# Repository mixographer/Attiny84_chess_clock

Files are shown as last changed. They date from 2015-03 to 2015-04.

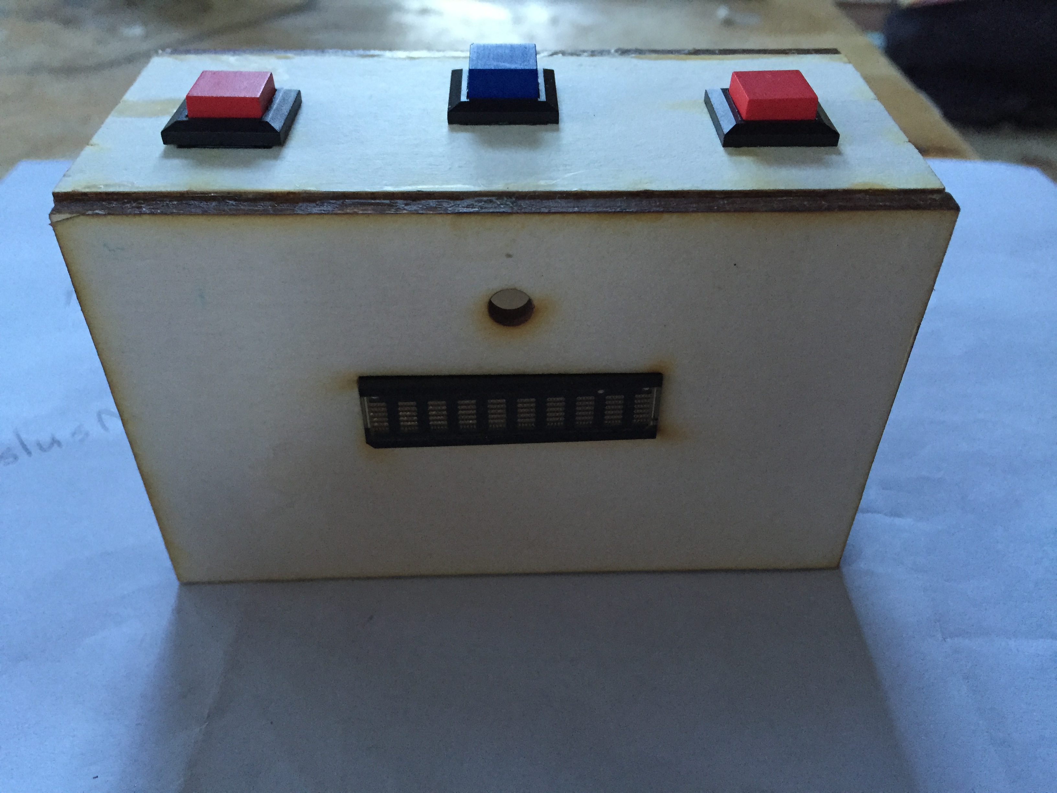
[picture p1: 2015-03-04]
Images/laser_cut_test.JPG

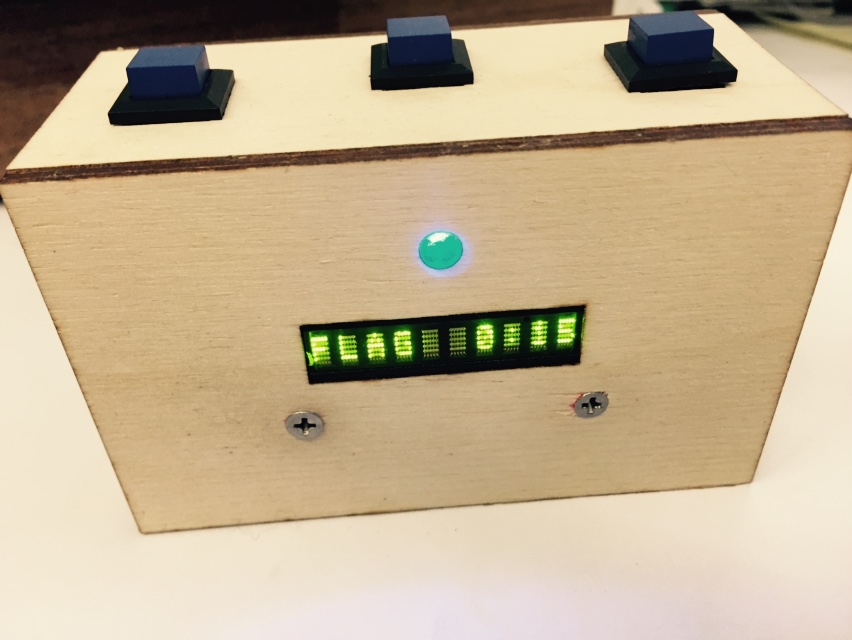
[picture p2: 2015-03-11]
Images/simple_clock.JPG

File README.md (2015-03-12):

# Attiny84 Chess Clock
A chess clock based on the Atmel Attiny84 micorcontroller.

This project is a simple chess clock based on the Atmel Attiny84 micoprocessor. It uses the SCD55104 LED Display 
module to display player times and user interface menus. The time periods are adjustable and the clock operated 
in three different modes. 

# Modes
## Sudden Death
In Sudden-death mode, your clock runs when it is your turn, and you lose when you run out of time. 

## Fischer Increment
In Fischer Increment mode, an increment is added at the start of each turn. In Fischer Increment mode you can actually 
add time to your total if you move faster than the increment amount. 

## Hourglass
In Hourglass mode, as one player's time goes down, the other player's time goes up. 

# Operation 
The Chess Clock has four buttons that are used during gameplay, and to set the parameters of the clock. 
1. Start/Reset
2. Player 1/Down
3. Player 2/Up
4. Pause/Enter

## Start
To begin using the clock press the Start/Reset button. 

## Set Time
You will be prompted to set the time period for the game with the text "Set Time:" Use the 'Player 1/Down' and 'Player 2/Up' buttons to set the time period. The default time is 2 minutes. The 'down' button reduces the time period while the 'up' button adds time. If the current time setting is 1:00 the down button will reduce the time period by 50%. The 'up' button adds 1 minute to the time period. 

When you have set the desired time period with the 'down' and 'up' buttons, press the 'Pause/Enter' button to accept the time period. 

## Set Mode
You will be prompted to set the mode of the clock.

#### Sudden Death
The default mode is Sudden Death or Guillotine. If you would like this mode simply hit the "Pause/Enter" button. 
The time period will be displayed for both players, and a play can begin. You can also scroll through the all modes with the 'Player 1/Down' and Player 2/Up' buttons. 

#### Fischer Increment
Fischer increment mode can be selected by pressing the 'Player 1/Down' or 'Player2/Up button at the 'Set Mode' prompt. When 'Fischer' is displayed on the clock you can accept Fischer delay mode by pressing the 'Pause/Enter' button. 

Set the increment. 
In Fischer increment mode, an increment period is required. The clock will prompt for the increment with the display "Inc?: 0:05." Set the desired increment with the 'Player 1/Down' and 'Player 2/Up' buttons. The increment adjusts in 1 second increments. Accept the increment with the 'Pause/Enter' button, the time period will be displayed and play can begin.

#### Hourglass
Hourglass mode can be selected by pressing the 'Player 1/Down' or 'Player2/Up' button at the 'Set Mode' prompt. Hourglass mode operates like an hourglass. As time is decreasing for one player, it is increasing for the other player. Once 'Hourglass' is displayed, press the 'Pause/Enter' button and play can begin. 

## Play
Once the time period and mode have been set, the clock is ready to use. When time runs out for a player and indicator light will illuminate and the word "FLAG" will appear for the player who ran out of time. After a short period of time the clock will shut down. To start a new game, press the 'Start/Reset' button. 

If during play, the clock needs to be paused for any reason, the 'Pause/Enter' will stop the clock at the current time. Play may be restarted by pressing either the 'Player1' or 'Player 2' button. Do not leave the clock paused for extended periods of time as that will prevent the clock from powering down and will drain the batteries. 

###Keywords
Chess Clock, DIY Chess Clock, Atmel, Attiny, Blitz, Bullet, Chess.

- - - 
### License
Licensed under the MIT License. See LICENSE.txt.

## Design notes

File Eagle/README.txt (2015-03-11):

I have tested 'scd55104_chess_clock.brd' and it works fine. I have not yet received 'Chess_Clock_Larger.brd' back from the board house, so I don't know if it works.

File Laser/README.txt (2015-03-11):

This SVG file (box_final_3mm_revised.svg) can be used as an enclosure for the Chess Clock. The original file box_final_3mm.svg had some errors in the side panels. Do not use that file.

I had enclosures cut from these files at Pololu.com. 

Note: I have not had this exact file laser cut. I have revised it to include the mounting holes 
on the front face. I have printed the drawings and compared them to the basic board 'scd55104_chess_clock.brd' They look good, but double check them if you are going to send them off to be cut. 

I have also not made an enclosure for 'Chess_Clock_Larger.brd' as of yet.

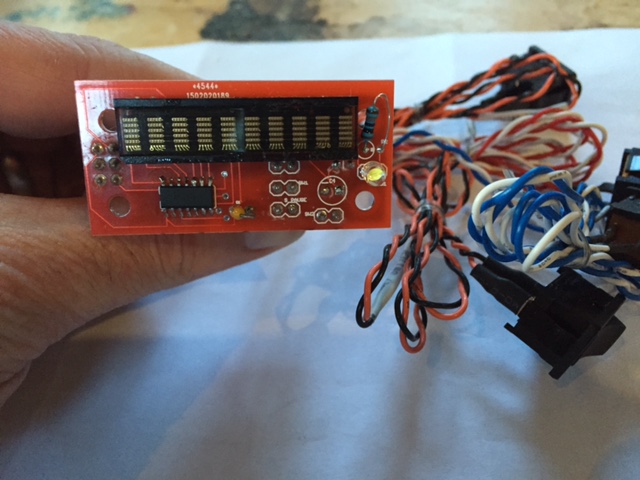
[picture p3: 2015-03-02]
Images/board_hookup.JPG

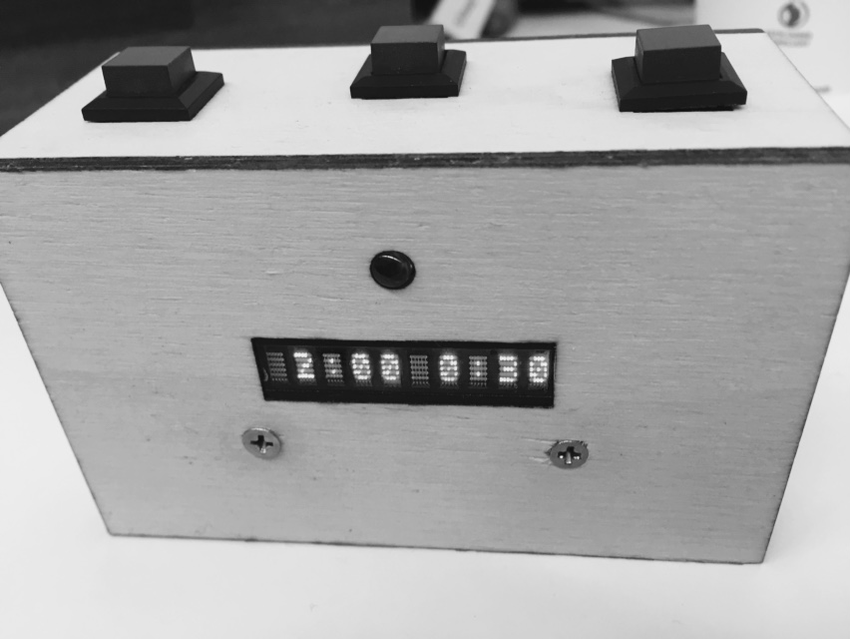
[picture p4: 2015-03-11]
Images/simple_clock_bw.JPG

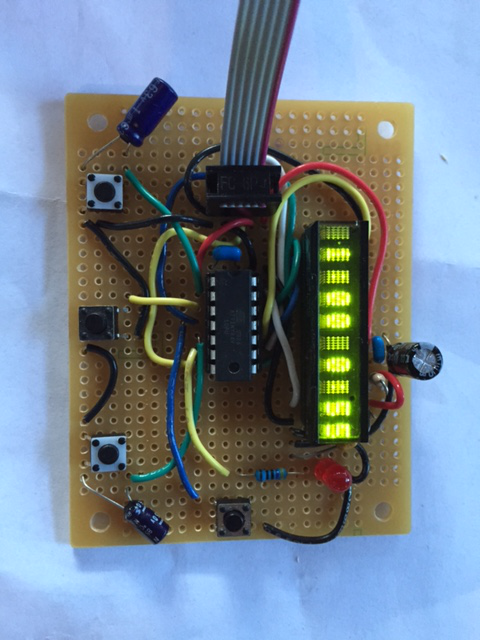
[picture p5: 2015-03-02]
Images/perf_board.JPG

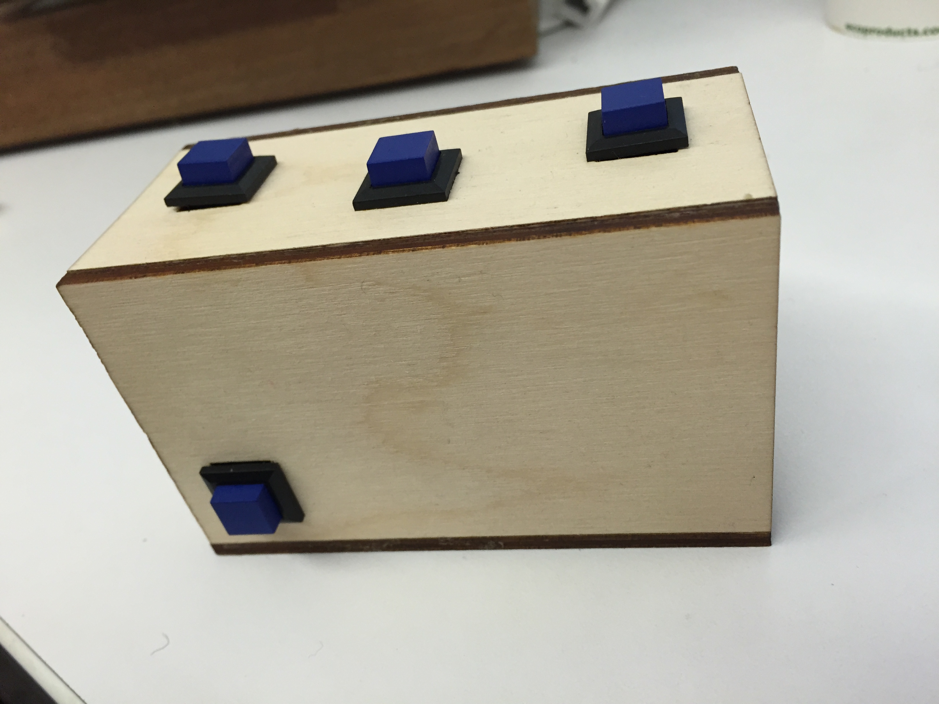
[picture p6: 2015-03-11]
Images/simple_clock_back.JPG

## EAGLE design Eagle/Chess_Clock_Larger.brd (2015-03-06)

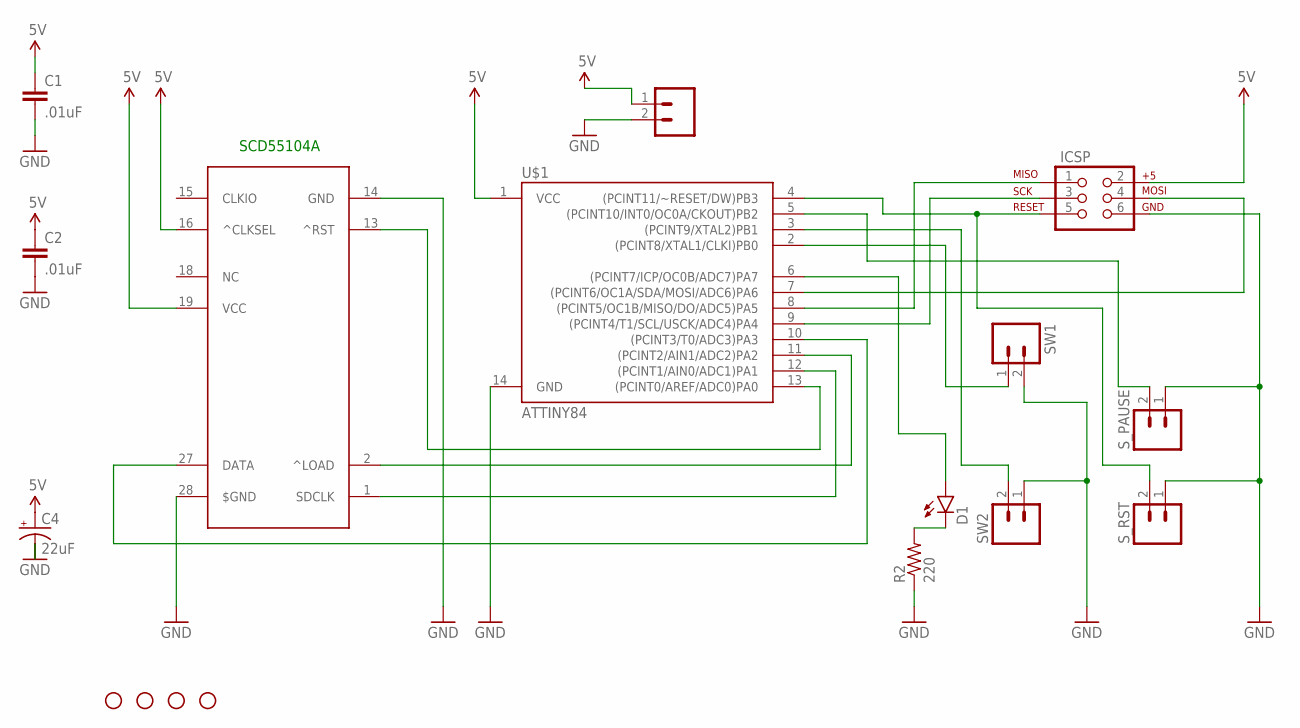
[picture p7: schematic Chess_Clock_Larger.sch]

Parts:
C1, C2: .01uF; CAP-PTH-SMALL
C4: 22uF; CPOL-RADIAL-10UF-25V
D1: LED5MM
ICSP: AVR_SPI_PRG_6PTH; 2X3
R2: 220; 1206
SCD55104A: SCD_55104A; SCD55104A
STANDOFF1, STANDOFF2, STANDOFF3, STANDOFF4: STAND-OFF
SW1, SW2, SW3: M02PTH; 1X02
S_PAUSE: M02PTH; 1X02
S_RST: M02PTH; 1X02
U$1: ATTINY84; SO14

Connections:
5V: C1.1, C2.1, C4.1 (+), ICSP.2, SCD55104A.16 (^CLKSEL), SCD55104A.19 (VCC), SW3.1, U$1.1 (VCC)
GND: C1.2, C2.2, C4.2 (-), ICSP.6, R2.1, SCD55104A.14 (GND), SCD55104A.28 ($GND), SW1.2, SW2.1, SW3.2, S_PAUSE.1, S_RST.1, U$1.14 (GND)
unnamed: D1.K (C), R2.2
unnamed: SCD55104A.13 (^RST), U$1.13 ((PCINT0/AREF/ADC0)PA0)
unnamed: ICSP.4, U$1.7 ((PCINT6/OC1A/SDA/MOSI/ADC6)PA6)
unnamed: ICSP.5, S_RST.2, U$1.4 ((PCINT11/~RESET/DW)PB3)
unnamed: ICSP.1, U$1.8 ((PCINT5/OC1B/MISO/DO/ADC5)PA5)
unnamed: ICSP.3, U$1.9 ((PCINT4/T1/SCL/USCK/ADC4)PA4)
unnamed: SCD55104A.1 (SDCLK), U$1.12 ((PCINT1/AIN0/ADC1)PA1)
unnamed: SCD55104A.2 (^LOAD), U$1.11 ((PCINT2/AIN1/ADC2)PA2)
unnamed: SW1.1, U$1.2 ((PCINT8/XTAL1/CLKI)PB0)
unnamed: SW2.2, U$1.3 ((PCINT9/XTAL2)PB1)
unnamed: S_PAUSE.2, U$1.5 ((PCINT10/INT0/OC0A/CKOUT)PB2)
unnamed: D1.A, U$1.6 ((PCINT7/ICP/OC0B/ADC7)PA7)
unnamed: SCD55104A.27 (DATA), U$1.10 ((PCINT3/T0/ADC3)PA3)

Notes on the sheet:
SCD55104A

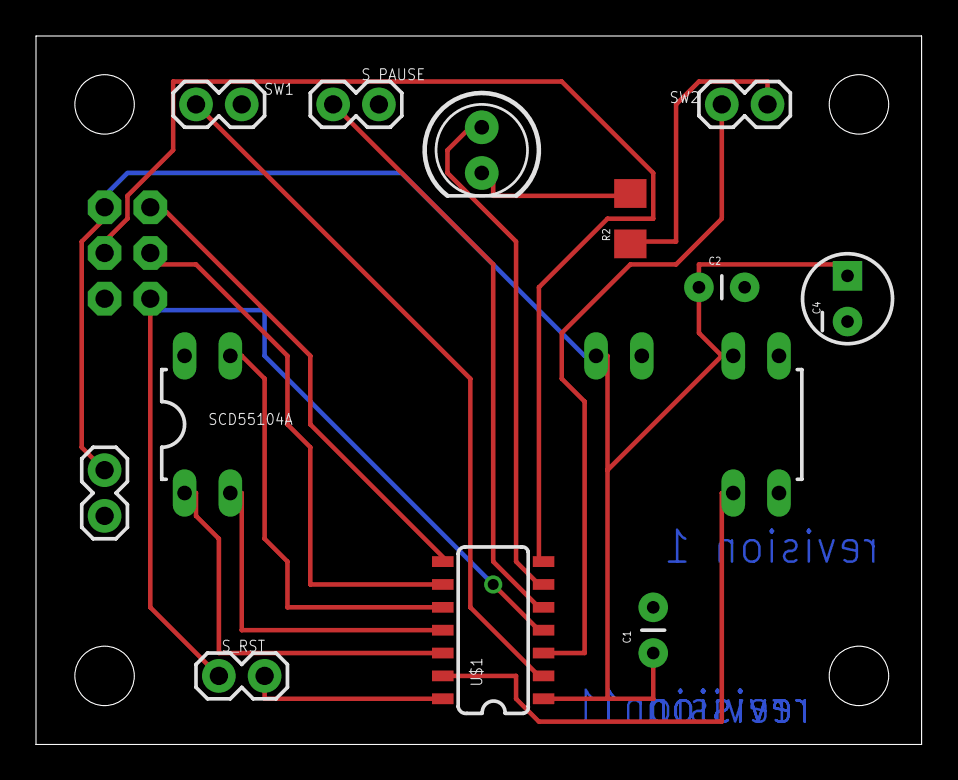
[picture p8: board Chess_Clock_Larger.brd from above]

Board: 2 copper layers, 49.2 x 39.4 mm, 17 parts (1 on the bottom side), 15 nets.

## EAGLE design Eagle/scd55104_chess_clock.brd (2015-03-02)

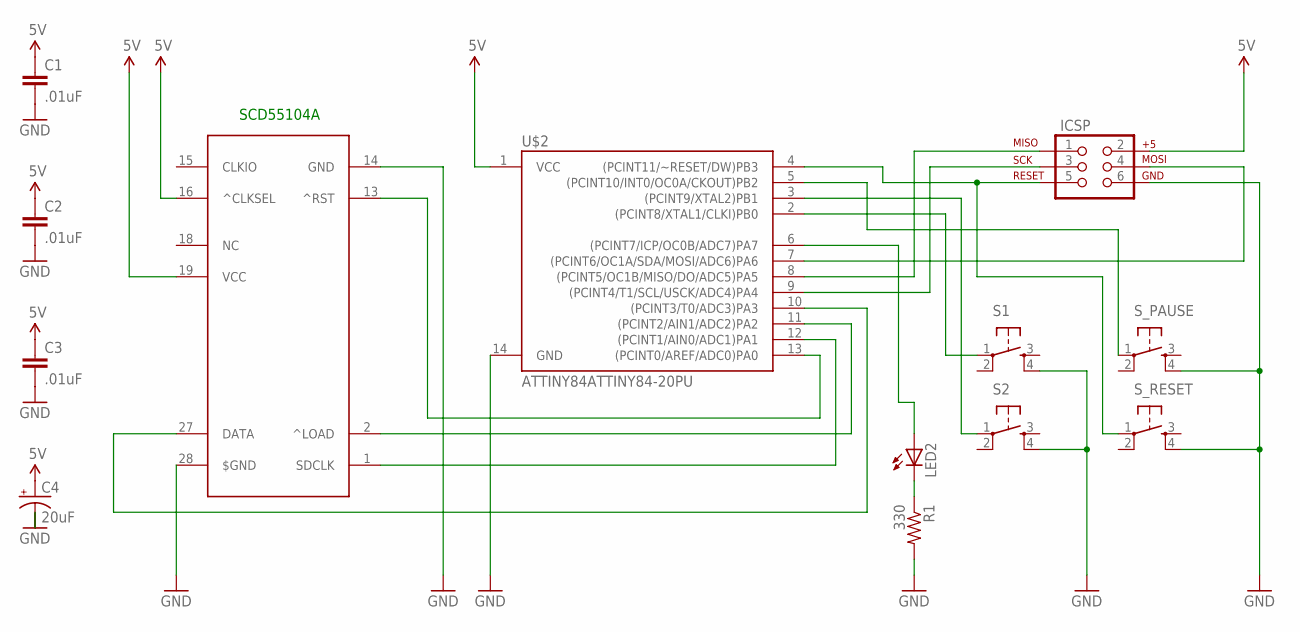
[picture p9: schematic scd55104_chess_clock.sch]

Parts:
C1, C2, C3: .01uF; CAP-PTH-SMALL
C4: 20uF; CPOL-RADIAL-10UF-25V
ICSP: AVR_SPI_PRG_6PTH; 2X3
LED2: LED3MM
R1: 330; AXIAL-0.4
S1, S2: TAC_SWITCHPTH; TACTILE-PTH
SCD55104A: SCD_55104A; SCD55104A
S_PAUSE: TAC_SWITCHPTH; TACTILE-PTH
S_RESET: TAC_SWITCHPTH; TACTILE-PTH
U$2: ATTINY84ATTINY84-20PU; DIL14

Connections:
5V: C1.1, C2.1, C3.1, C4.1 (+), ICSP.2, SCD55104A.16 (^CLKSEL), SCD55104A.19 (VCC), U$2.1 (VCC)
GND: C1.2, C2.2, C3.2, C4.2 (-), ICSP.6, R1.P$2 (2), S1.4, S2.4, SCD55104A.14 (GND), SCD55104A.28 ($GND), S_PAUSE.4, S_RESET.4, U$2.14 (GND)
unnamed: SCD55104A.13 (^RST), U$2.13 ((PCINT0/AREF/ADC0)PA0)
unnamed: ICSP.4, U$2.7 ((PCINT6/OC1A/SDA/MOSI/ADC6)PA6)
unnamed: ICSP.5, S_RESET.1, U$2.4 ((PCINT11/~RESET/DW)PB3)
unnamed: ICSP.1, U$2.8 ((PCINT5/OC1B/MISO/DO/ADC5)PA5)
unnamed: ICSP.3, U$2.9 ((PCINT4/T1/SCL/USCK/ADC4)PA4)
unnamed: SCD55104A.1 (SDCLK), U$2.12 ((PCINT1/AIN0/ADC1)PA1)
unnamed: SCD55104A.2 (^LOAD), U$2.11 ((PCINT2/AIN1/ADC2)PA2)
unnamed: S1.1, U$2.2 ((PCINT8/XTAL1/CLKI)PB0)
unnamed: S2.1, U$2.3 ((PCINT9/XTAL2)PB1)
unnamed: LED2.K (C), R1.P$1 (1)
unnamed: S_PAUSE.1, U$2.5 ((PCINT10/INT0/OC0A/CKOUT)PB2)
unnamed: LED2.A, U$2.6 ((PCINT7/ICP/OC0B/ADC7)PA7)
unnamed: SCD55104A.27 (DATA), U$2.10 ((PCINT3/T0/ADC3)PA3)

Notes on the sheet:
SCD55104A

Board: 2 copper layers, 13 parts (0 on the bottom side), 15 nets, no tracks yet.

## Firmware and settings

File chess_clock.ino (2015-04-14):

#include <avr/sleep.h>
#include <avr/pgmspace.h>
#include <avr/power.h>


//standard ascii 5x5 font
static unsigned char Font5x5[] PROGMEM = {
  0x00, 0x20, 0x40, 0x60, 0x80,
  0x04, 0x24, 0x44, 0x60, 0x84,
  0x0A, 0x2A, 0x40, 0x60, 0x80,
  0x0A, 0x3F, 0x4A, 0x7F, 0x8A,
  0x0F, 0x34, 0x4E, 0x65, 0x9E,
  0x19, 0x3A, 0x44, 0x6B, 0x93,
  0x08, 0x34, 0x4D, 0x72, 0x8D,
  0x04, 0x24, 0x40, 0x60, 0x80,
  0x02, 0x24, 0x44, 0x64, 0x82,
  0x08, 0x24, 0x44, 0x64, 0x88,
  0x15, 0x2E, 0x5F, 0x6E, 0x95,
  0x04, 0x24, 0x5F, 0x64, 0x84,
  0x00, 0x20, 0x40, 0x64, 0x84,
  0x00, 0x20, 0x4E, 0x60, 0x80,
  0x00, 0x20, 0x40, 0x60, 0x84,
  0x01, 0x22, 0x44, 0x68, 0x90,
  0x0E, 0x33, 0x55, 0x79, 0x8E,
  0x04, 0x2C, 0x44, 0x64, 0x8E,
  0x1E, 0x21, 0x46, 0x68, 0x9F,
  0x1E, 0x21, 0x4E, 0x61, 0x9E,
  0x06, 0x2A, 0x5F, 0x62, 0x82,
  0x1F, 0x30, 0x5E, 0x61, 0x9E,
  0x06, 0x28, 0x5E, 0x71, 0x8E,
  0x1F, 0x22, 0x44, 0x68, 0x88,
  0x0E, 0x31, 0x4E, 0x71, 0x8E,
  0x0E, 0x31, 0x4F, 0x62, 0x8C,
  0x00, 0x24, 0x40, 0x64, 0x80,
  0x00, 0x24, 0x40, 0x6C, 0x80,
  0x02, 0x24, 0x48, 0x64, 0x82,
  0x00, 0x3F, 0x40, 0x7F, 0x80,
  0x08, 0x24, 0x42, 0x64, 0x88,
  0x0E, 0x31, 0x42, 0x64, 0x84,
  0x0E, 0x35, 0x57, 0x70, 0x8E,
  0x04, 0x2A, 0x5F, 0x71, 0x91,   
  0x1E, 0x29, 0x4E, 0x69, 0x9E,   
  0x0F, 0x30, 0x50, 0x70, 0x8F,   
  0x1E, 0x29, 0x49, 0x69, 0x9E,   
  0x1F, 0x30, 0x5E, 0x70, 0x9F,   
  0x1F, 0x30, 0x5E, 0x70, 0x90,   
  0x0F, 0x30, 0x53, 0x71, 0x8F,   
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
};

//Display pins 
const int loadPin = 8;
const int sdataPin = 7;
const int sdclkPin = 9;
const int resetPin = 10;
const int ledPin = 3;
//Button Pins
const int button1 = 0;
const int button2 = 2;
const int button3 = 1; 

//for proto board:
//const int button2 = 1;
//const int button3 = 2; 

//Initial Times
double player1Time = 91000;
double player2Time = 91000;
long increment = 5000;
int player1Minutes = 0;
int player1Seconds = 0;
double player1LastCheck = millis();
int player2Minutes = 0;
int player2Seconds = 0;
double player2LastCheck = millis();
//Who's turn is it? 
boolean isPlayer1Turn = false;
boolean isPlayer2Turn = false;
boolean gameOver = false;
// are various modes/times set? Fischer, Bronstein etc
boolean modeSet = false;
boolean timeSet = false;
boolean incrementSet = false;
//Buttons State
boolean button1state = 0;
boolean lastButton1state = 0;
boolean button2state = 0;
boolean lastButton2state = 0;
boolean button3state = 0;
boolean lastButton3state = 0;
//Buffers to hold player times
char player1DisplayTime[6] = "";
char player2DisplayTime[6] = "";
char incrementDisplayTime[6] = "";
//store the different modes here
//mode 1 is Fischer, 2 is Sudden Death, 3 Hourglass, 
byte gameMode = 2 ;

void setup(){
  pinMode(button1, INPUT_PULLUP);
  pinMode(button2, INPUT_PULLUP);
  pinMode(button3, INPUT_PULLUP);
  //pins for controlling the display:
  pinMode(resetPin, OUTPUT);
  pinMode(sdataPin, OUTPUT);
  pinMode(sdclkPin, OUTPUT);
  pinMode(ledPin, OUTPUT);
  pinMode(loadPin, OUTPUT);
  //reset the display
  digitalWrite(resetPin, LOW);
  delay(200);
  digitalWrite(resetPin, HIGH);
  setBrightness(4);
  displayBegin();
  delay(30);
}

//These are the functions that control the display:
void writeByte(const char a){
  digitalWrite(loadPin, LOW); 
  for (int b = 0; b <= 7; b++) {
    digitalWrite(sdataPin, bitRead(a, b));
    digitalWrite(sdclkPin, LOW);
    digitalWrite(sdclkPin, HIGH);
  }
  digitalWrite(loadPin, HIGH); 
}
  
  
void writeChar(byte c){
  int d = (c - 0x20) *5;
  for (int i = 0; i < 5; i++) {
    writeByte(pgm_read_byte(&Font5x5[d + i]));
  }
}
  
  
void displayChar(const char myChar, int myPos){
  writeByte(0xB0 + myPos);
  writeChar(myChar);
}

void setBrightness(int brightLevel){
  writeByte(0xF7 - brightLevel);
}

void powerDown(){
  writeByte(0xFF);
}

void pauseGame(){
  isPlayer1Turn = false;
  isPlayer2Turn = false;
  
}

void displayBegin()
{
  //reset the display
  writeByte(0xC0);
} // end of display functions


void setMode(){ //set the mode
    // modes: 1=Fischer....  2=guillotine... 3= hourglass
    displayChar('S', 0);
    displayChar('e', 1);
    displayChar('t', 2);
    displayChar(' ', 3);
    displayChar('M', 4);
    displayChar('o', 5);
    displayChar('d', 6);
    displayChar('e', 7);
    displayChar(':', 8);
    displayChar(' ', 9);
    delay(500);
    while(modeSet == false){
       button1state = digitalRead(button1);
       button2state = digitalRead(button2);
       button3state = digitalRead(button3);
         if (button2state != lastButton2state){
           if (button2state == LOW){
             // for sudden death, don't set gameMode
              delay(10);
              modeSet = true;
              delay(50);
           }
           delay(50);
           lastButton2state = button2state;
      
         } else if (button1state != lastButton1state){
           if (button1state == LOW){
              gameMode --; 
              if (gameMode < 1) { 
                 gameMode = 3;
              }
          }
          delay(50);
          lastButton1state = button1state;
      
         } else if (button3state != lastButton3state){
            if (button3state == LOW){
              gameMode ++; //delay 
              if (gameMode > 3 ) { 
                 gameMode = 1;
              }
         }
         delay(50);
         lastButton3state = button3state;
         
       } else {
       
       if (gameMode == 1){
              delay(10);
              displayChar('F', 0);
              displayChar('i', 1);
              displayChar('s', 2);
              displayChar('c', 3);
              displayChar('h', 4);
              displayChar('e', 5);
              displayChar('r', 6);
              displayChar(' ', 7);
              displayChar(' ', 8);
              displayChar(' ', 9);
       
       } else if (gameMode == 2){
              delay(10);
              displayChar('S', 0);
              displayChar('u', 1);
              displayChar('d', 2);
              displayChar('d', 3);
              displayChar('e', 4);
              displayChar('n', 5);
              displayChar('D', 6);
              displayChar('e', 7);
              displayChar('a', 8);
              displayChar('t', 9);
       }  else if (gameMode == 3){
              delay(10);
              displayChar('H', 0);
              displayChar('o', 1);
              displayChar('u', 2);
              displayChar('r', 3);
              displayChar('g', 4);
              displayChar('l', 5);
              displayChar('a', 6);
              displayChar('s', 7);
              displayChar('s', 8);
              displayChar(' ', 9);
     }
}
}
} // end setMode

 
 
void setTime(){
  player1Time = 120000;
  player2Time = 120000;
  displayChar('S', 0);
  displayChar('e', 1);
  displayChar('t', 2);
  displayChar(' ', 3);
  displayChar('T', 4);
  displayChar('i', 5);
  displayChar('m', 6);
  displayChar('e', 7);
  displayChar(':', 8);
  displayChar(' ', 9);
  //boolean timeSet = false;
  while(timeSet == false){
   button1state = digitalRead(button1);
   button2state = digitalRead(button2);
   button3state = digitalRead(button3);
   if (button2state != lastButton2state){
      if (button2state == LOW){
      delay(10);
      refreshClocks();
      delay(500);
      timeSet = true;
      }
      delay(250);
      lastButton2state = button2state;  
    } else if (button1state != lastButton1state){
      if (button1state == LOW){
        if (player1Time <= 60000){
          player1Time -= (player1Time/2);
          player2Time -= (player2Time/2);
          refreshClocks();
          } else {
          player1Time -= 60000;
          player2Time -= 60000;
          refreshClocks();
          }
      }
      delay(250);
      lastButton1state = button1state;
      
    } else if (button3state != lastButton3state){
      if (button3state == LOW){
      player1Time += 60000;
      player2Time += 60000;
      refreshClocks();
      }
      delay(250);
      lastButton3state = button3state;
    } else {}
  } 
} //end setTime

// for Fischer mode only
void setIncrement(){
  //player1Time = 120000;
  //player2Time = 120000;
  displayChar('S', 0);
  displayChar('e', 1);
  displayChar('t', 2);
  displayChar(' ', 3);
  displayChar('I', 4);
  displayChar('n', 5);
  displayChar('c', 6);
  displayChar('.', 7);
  displayChar(':', 8);
  displayChar(' ', 9);
 
  while(incrementSet == false){
   button1state = digitalRead(button1);
   button2state = digitalRead(button2);
   button3state = digitalRead(button3);
   if (button2state != lastButton2state){
      if (button2state == LOW){
      delay(10);
      refreshClocks();
      delay(500);
      incrementSet = true;
      }
      delay(100);
      lastButton2state = button2state;
      
    } else if (button1state != lastButton1state){
      if (button1state == LOW){
      increment -= 1000;
      }
      delay(100);
      lastButton1state = button1state;
      
    } else if (button3state != lastButton3state){
      if (button3state == LOW){
      increment += 1000;
      }
      delay(100);
      lastButton3state = button3state;
    } else {
      displayIncrement();
    }
  } 
} //end setIncrement

 
void loop(){
  if (timeSet == false){
    setTime();
  }
  if (modeSet == false){
    setMode();
  }
  
  if (gameMode == 1){
    if(incrementSet == false){
    setIncrement();
    }
  }
  
  button1state = digitalRead(button1);
  button2state = digitalRead(button2);
  button3state = digitalRead(button3);
  if (button3state != lastButton3state){
  if (button3state == LOW) {
    startPlayer1Turn();
  }
  lastButton3state = button3state;
  }
  if (button1state != lastButton1state){
    if (button1state == LOW) {
    startPlayer2Turn();
    }
    lastButton1state = button1state;
  }
  if (button2state == LOW) {
    pauseGame();
  }
  if (isPlayer1Turn) {
    updatePlayer1Time();
  } else if (isPlayer2Turn) {
    updatePlayer2Time();
  
  } else {
  }
  updateDisplay();
} // end loop()

void updateDisplay(){;
    for(int i = 0; i < 5; i++) {
      displayChar(player1DisplayTime[i], i );
    }
    for(int i = 0; i < 5; i++){
      displayChar(player2DisplayTime[i], i+5 );
    }
    setBrightness(7);
    delay(10);
}

void updateIncrementDisplay(){
   for(int i = 0; i < 5; i++){
      displayChar(incrementDisplayTime[i], i+5 );
    }
    setBrightness(7);
    delay(10);
}
  
void displayIncrement(){
  int incrementMinutes = floor(increment / 60000);
  int incrementSeconds = floor(increment / 1000) - incrementMinutes * 60;
  sprintf(incrementDisplayTime, "%2d:%02d", incrementMinutes, incrementSeconds);
  updateIncrementDisplay();
}
  
void refreshClocks(){
  player1Minutes = floor(player1Time / 60000);
  player1Seconds = floor(player1Time / 1000) - player1Minutes * 60;
  sprintf(player1DisplayTime, "%2d:%02d", player1Minutes, player1Seconds);
  player2Minutes = floor(player2Time / 60000);
  player2Seconds = floor(player2Time / 1000) - player2Minutes * 60;
  sprintf(player2DisplayTime, "%2d:%02d", player2Minutes, player2Seconds);
  updateDisplay();
}
  
    
void updatePlayer1Time(){
  player1Time -= ((millis() - player1LastCheck));
  // for hourglass, could I add to player2Time as I subtract it here? 
  if (gameMode == 3){
     player2Time += ((millis() - player1LastCheck));
  }
  player1LastCheck = millis();
  if (player1Time <= 0) {
    gameOver = true;
    flagPlayer(1);
    return;
  }
  
  refreshClocks();
}
  

void flagPlayer(int playerNumber){
  digitalWrite(3, HIGH);
  isPlayer1Turn = false;
  isPlayer2Turn = false;
    if (playerNumber == 1){
      displayChar('F', 0);
      displayChar('L', 1);
      displayChar('A', 2);
      displayChar('G', 3);
      displayChar(' ', 4);
    }else{
      displayChar(' ', 5);
      displayChar('F', 6);
      displayChar('L', 7);
      displayChar('A', 8);
      displayChar('G', 9);
    }
    delay(15000);
    powerDown();
    digitalWrite(3, LOW);
    //write everything low, we're going to sleep:
    //This got it to uA levels.
    pinMode(button1, INPUT);
    pinMode(button2, INPUT);
    pinMode(button3, INPUT);
    digitalWrite(button1, LOW);
    digitalWrite(button2, LOW);
    digitalWrite(button3, LOW);
    ADCSRA = 0;
    power_all_disable();
    set_sleep_mode(SLEEP_MODE_PWR_DOWN);
    //delay(100);
    sleep_enable();
    sleep_cpu();
}    

void updatePlayer2Time(){
  player2Time -= ((millis() - player2LastCheck));
  // for hourglass, could I add to player1Time as I subtract it here? 
  if (gameMode == 3){
     player1Time += ((millis() - player2LastCheck));
  }
  player2LastCheck = millis();
  if (player2Time <= 0) {
    gameOver = true;
    flagPlayer(2);
    return;
  }
  refreshClocks();
  }
  
//}
   
void startPlayer1Turn () {
  if (isPlayer1Turn) {
    return;
  }
  //unsigned long startP1turn = millis();
  if (gameMode == 1){
    player1Time += increment;
  }
//  if(gameMode == 2){
//    if (millis() - startP1turn < 3000){
//      isPlayer1Turn = false;
//      isPlayer2Turn = false;
//    }
//  }
  isPlayer1Turn = true;
  isPlayer2Turn = false;
  player1LastCheck = millis();
}

void startPlayer2Turn () {
  if (isPlayer2Turn) {
    return;
  }
  //unsigned long startP2turn = millis();
  if (gameMode == 1){
    player2Time += increment;
  } 
//  if(gameMode == 2){
//    if (millis() - startP2turn < 3000){
//      isPlayer1Turn = false;
//      isPlayer2Turn = false;
//    }
//  }
  isPlayer2Turn = true;
  isPlayer1Turn = false;
  player2LastCheck = millis();
}

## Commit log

2015-02-28 Initial commit of the Arduino Sketch.
2015-03-02 Images of some prototype stages
2015-03-02 Adding Eagle files, including schematic and board file.
    [scd55104_chess_clock.brd, scd55104_chess_clock.sch]
2015-03-02 Adding datasheet for scd55104A LED displays.
2015-03-03 Adding the svg file used to cut the enclosures.
2015-03-04 The correct file for the enclosure is box_final_3mm_revised.svg. This file should be cut out of 1/8" ply, as close to 3mm as possible.
2015-03-04 Adding an image of the first laser cut test enclosure.
2015-03-05 Added mounting holes to front panel
2015-03-05 changed the size of the LED hole, for an interference fit.
2015-03-06 adding a lager board for easier assembly.
    [Chess_Clock_Larger.brd, Chess_Clock_Larger.sch]
2015-03-11 Adding images of the clock in the laser cut enclosure.
2015-03-11 added note about untested nature of the current drawings.
2015-03-11 Added readem.txt, noting I haven't tested with the larger board.
2015-03-12 User testing showed that the mode setting should be with Up/Down/Enter buttons, just like adding and subtracting time in setTime. I have changed it to that menu method.
    TODO: should make gameMode 2 into a real mode rather than just a default mode.
2015-03-12 Set GameMode to '2' so that gameMode -- actually means somthing. starting with gameMode undefined didn't work!
    [chess_clock.ino]
2015-03-17 Adding in some de-bounce delays for the bouncy buttons I used.
2015-04-14 Had a bug in Fischer Mode where the time was always set to 2:00. Fixed.
    [chess_clock.ino]

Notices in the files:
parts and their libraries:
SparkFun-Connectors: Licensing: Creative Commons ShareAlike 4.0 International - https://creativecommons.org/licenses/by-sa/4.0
